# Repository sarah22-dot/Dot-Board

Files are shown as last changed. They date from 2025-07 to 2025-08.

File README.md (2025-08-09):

# Dot-Board
dot‑Board was never meant to be just another mechanical keyboard. It was built for a moment, for a vibe, for a challenge. The entire thing came together during Hack Club’s Highway event, where we were supposed to not just build something, but make it our own. I put my energy into what I love the most designing the PCB and modelling the case. While others were wiring or coding, I was deep inside Fusion 360 and EasyEDA Pro, trying to make sure every detail felt precise and intentional.

It started off as a late-night sketch in my notes app. I wanted something compact but not boring, logical but still unique. A grid layout made the most sense ortholinear, neat rows and columns, the kind of layout that just looks satisfying when you view it from topdown. I fired up EasyEDA Pro and began building the schematic from scratch. No template, no copy-paste from someone else's build. I dropped the Pro Micro, mapped each row and column with proper matrix logic, and added footprints for diodes and a rotary encoder. The goal was clarity and flow every trace should feel like it belongs.



Once the schematic was wired up, I moved to the PCB layout view and began placing the switches in a tight grid. I spent hours just nudging parts to get clean alignment. I added a compact reset switch footprint, labeled the layers carefully, and did final cleanup to make sure the silkscreen looked aesthetic. I chose 1.6 mm board thickness, standard FR4. Then I exported the Gerbers and submitted them to JLCPCB with the deadline pressure running in the back of my head.





At the same time, I jumped into Fusion 360 to work on the case. The case wasn’t just a box to hold the PCB it had to be clean, functional, and vibe with the layout. I designed a simple sandwich-style build, with a flat top plate that holds the switches snugly, and a lower base tray with screw mounts. I gave it slight curvature along the sides, nothing dramatic, just enough so it wouldn’t feel sharp in the hand. There was a cutout for the USB port and small standoffs inside so the board would sit at the right height without needing extra spacers.






The project wasn’t about perfection—it was about putting something together that you could be proud of. I didn’t assemble the keyboard physically, but seeing the design take shape and sharing it with others during the event felt like enough. I handed over the filesGerbers, STEP files, BOM references to the rest of the team or anyone who wanted to build it physically. It felt good knowing someone out there could finish what I started and maybe even add their own twist to it.



dot‑Board, to me, represents the kind of project that grows in a weekend but stays in your mind for a long time. The kind where you learn more by doing than reading. I figured out new quirks in EasyEDA, got better at 3D design in Fusion, and actually worked on finishing something under a deadline with that good kind of pressure. It’s not just a keyboard—it’s a slice of that Hack Club energy, captured in traces and plastic.





Even though I didn’t solder a single switch for this board, I still feel connected to every part of it because I designed it to work, to look sharp, and to invite others to complete it. That’s the spirit of dot‑Board. It starts with a dot, but you never know where it goes.

## updated case









## added logo on top


## BOM
| Component | Source & Link | Qty | Total Cost (INR) | Total Cost (USD) |
| --- | --- | ----- | --- | --- |
| Gateron Yellow Mechanical Switches | Amazon.in (70‑pack) | 62 | ₹2,400 | \$25 |
| PBT Dye‑sublimated Keycaps (Black) | neomacro.in | 62 | ₹2,550 | \$30 |
| Kailh Hot‑swap Sockets | neomacro.in | 62 | ₹1,300 | \$15.50 |
| Rotary Encoders | neomacro.in | 2 | ₹340 | \$4 |
| Encoder Knobs | neomacro.in | 2 | ₹170 | \$2 |
| Custom PCB (5 pcs) – Gerber\_Y51 | JLCPCB via EasyEDA  | 5 | ₹2,550 | \$30 |
| Arduino Pro Micro (Clone) | Amazon.in | 1 | ₹850 | \$10 |
| Diode Kit (1N4148, 100 pcs) | Amazon.in | 1 | ₹85 | \$1 |
| Screws, Standoffs, Mounting HW | Local/kit | 1 set | ₹150 | \$1.80 |
| Shipping (PCB from JLCPCB) | JLCPCB | 1 | ₹425 | \$5.33 |
| **Total** | | | **₹10,820** | **\$124.63** |

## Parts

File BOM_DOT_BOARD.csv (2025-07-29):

Component | Source & Link | Qty | Total Cost (INR) | Total Cost (USD)
Gateron Yellow Mechanical Switches | Amazon.in | 62 | 2400.0 | 25.0
PBT Dye‑sublimated Keycaps (Black) | neomacro.in | 62 | 2550.0 | 30.0
Kailh Hot‑swap Sockets | neomacro.in | 62 | 1300.0 | 15.5
Rotary Encoders | neomacro.in | 2 | 340.0 | 4.0
Encoder Knobs | neomacro.in | 2 | 170.0 | 2.0
Custom PCB (5 pcs) – Gerber_Y51 | JLCPCB via EasyEDA | 5 | 2550.0 | 30.0
Arduino Pro Micro (Clone) | Amazon.in | 1 | 850.0 | 10.0
Diode Kit (1N4148, 100 pcs) | Amazon.in | 1 | 85.0 | 1.0
Screws, Standoffs, Mounting HW | Local / Maker Kit | 1 set | 150.0 | 1.8
Shipping (PCB from JLCPCB) | JLCPCB | 1 | 425.0 | 5.33
Total |  |  | 10820.0 | 124.63

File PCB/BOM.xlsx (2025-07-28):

No. | Quantity | Comment | Designator | Footprint | Value | Manufacturer Part | Manufacturer | Supplier Part | Supplier
1 | 14 | C1206C105K5RACTU | C1,C2,C3,C4,C5,C6,C7,C8,C9,C10,C11,C12,C13,C14 | Capacitor_SMD:C_1206_3216Metric_Pad1.33x1.80mm_HandSolder
2 | 48 | 1N4148W | D1,D2,D3,D4,D5,D6,D7,D8,D9,D10,D11,D12,D13,D14,D15,D16,D17,D18,D19,D20,D21,D22,D23,D24,D25,D26,D27,D28,D29,D30,D31,D32,D33,D34,D35,D36,D37,D38,D39,D40,D41,D42,D43,D44,D45,D46,D47,D48 | Diode_SMD:D_SOD-123
3 | 10 | MountingHole | H1,H2,H3,H4,H5,H6,H7,H8,H9,H10 | kbd:M2_HOLE
4 | 2 | Conn_01x01_Female | J1,JN | Connector_Pin:Pin_D0.9mm_L10.0mm_W2.4mm_FlatFork
5 | 1 | Conn_01x03_Female | J3 | Connector_PinHeader_2.00mm:PinHeader_1x03_P2.00mm_Vertical
6 | 14 | WS2812B | LED1,LED2,LED3,LED4,LED5,LED6,LED7,LED8,LED9,LED10,LED11,LED12,LED13,LED14 | LED_SMD:LED_WS2812B_PLCC4_5.0x5.0mm_P3.2mm
7 | 1 | SW_KBD | Reset1 | kbd:SW_SPST_RS-282G05A3-SM
8 | 44 | MX_SW_HS | SW1,SW2,SW3,SW4,SW5,SW6,SW7,SW8,SW9,SW10,SW11,SW12,SW13,SW14,SW15,SW16,SW17,SW18,SW19,SW20,SW21,SW22,SW23,SW24,SW25,SW26,SW27,SW28,SW29,SW30,SW31,SW32,SW33,SW34,SW35,SW36,SW39,SW40,SW43,SW44,SW45,SW46,SW47,SW48 | Switch_Keyboard_Hotswap_Kailh:SW_Hotswap_Kailh_MX_1.00u
9 | 2 | RotaryEncoder_Switch | SW37,SW38 | Rotary_Encoder:RotaryEncoder_Alps_EC11E-Switch_Vertical_H20mm
10 | 2 | MX_SW_HS | SW41,SW42 | Switch_Keyboard_Hotswap_Kailh:SW_Hotswap_Kailh_MX_1.50u_90deg
11 | 1 | MSK12C02 | SW49 | kbd:MSK12C02
12 | 1 | SS12D00 | SW_TOG1 | kbd:SS12D00
13 | 1 | ProMicro | U1 | kbd:ProMicro_v3.5

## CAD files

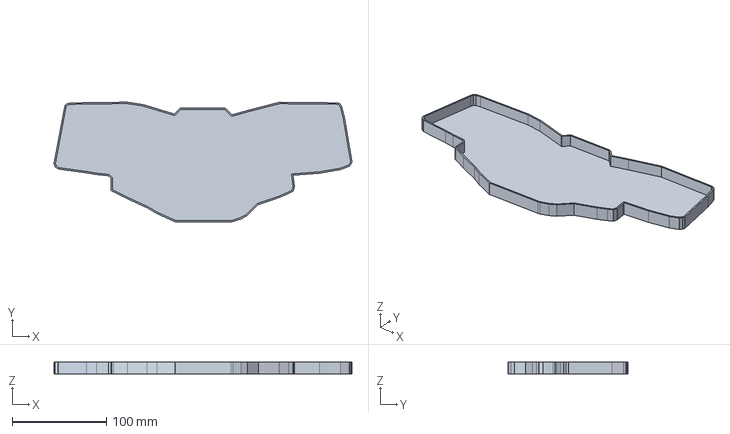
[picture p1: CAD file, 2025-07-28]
CAD/Back.step
317.0 x 127.4 x 12.7 mm

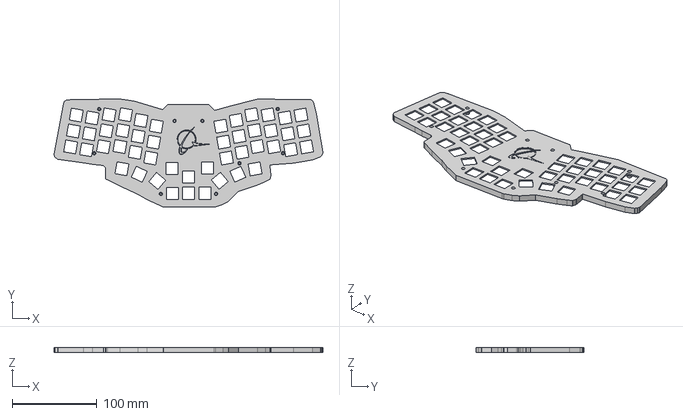
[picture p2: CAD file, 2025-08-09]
Production/Top v2.step
317.0 x 127.4 x 6.35 mm

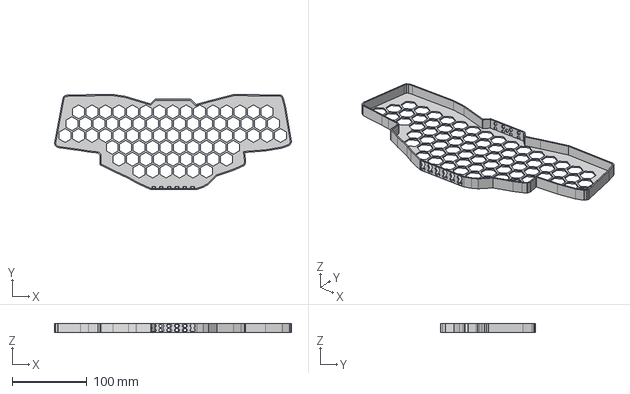
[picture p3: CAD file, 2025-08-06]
Production/base v2.step
317.0 x 127.4 x 12.7 mm

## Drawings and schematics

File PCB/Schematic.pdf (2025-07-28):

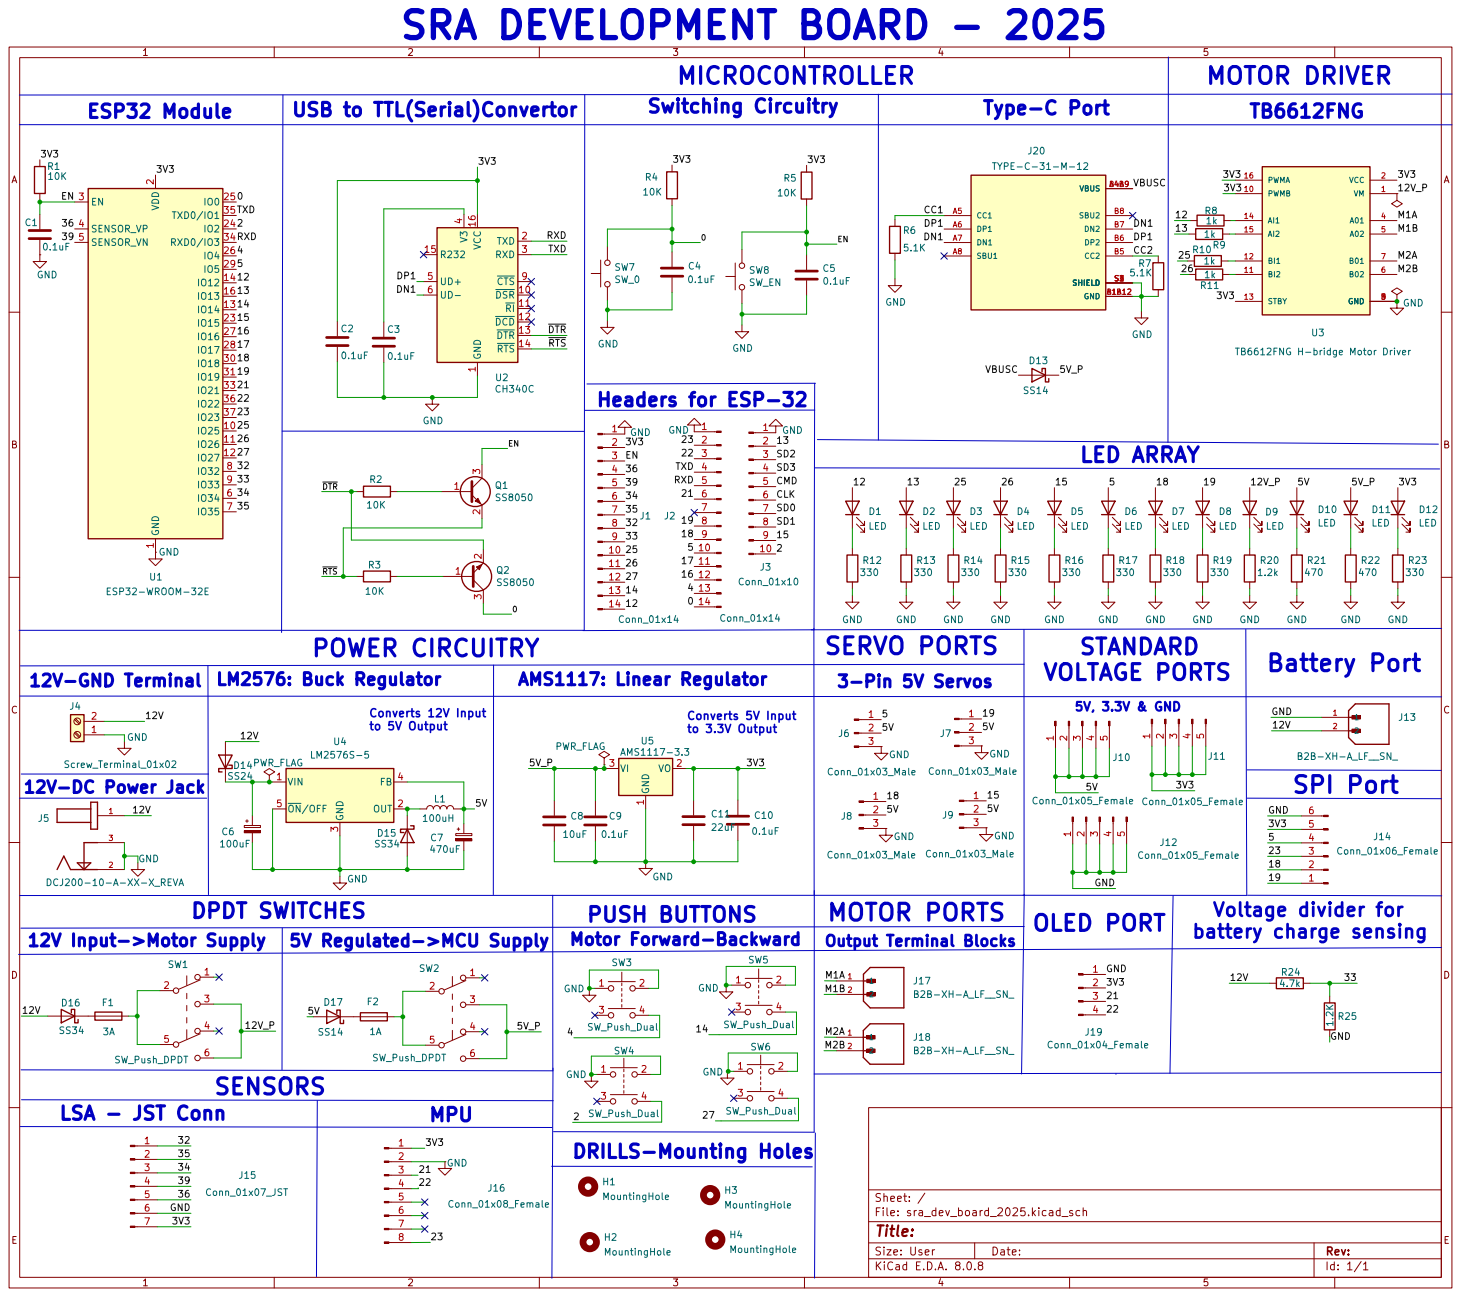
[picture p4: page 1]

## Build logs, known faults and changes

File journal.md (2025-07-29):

## Dot‑Board Build Journal
---
Title: "Dot Board"
Author: "Sarah"
Description: "Custom keeeb
created_at: "2025-07-25"
Total time spent: 22.5
---

## July 22 – First Schematic (7.5 hours)
It was one of those nights when the rain had just stopped, my playlist was stuck on Lo-fi beats, and I was just sitting on my bed, staring at my half dead old keyboard. The thing looked like it had survived a zombie apocalypse. And the typing feel? Ugh, don’t even ask. Every keystroke felt like I was arguing with a soggy biscuit. That’s when something clicked. Not on the keyboard, though. In my brain. I thought, “Why not just make my own keyboard?” Not just assemble parts, but actually design everything—the PCB, the schematic, and the whole look. And thus, the dot‑Board idea was born, right there under my cheap fairy lights.

I opened up EasyEDA Pro and started a new project called “dot-Board v0.” No fancy names, just straight to the point. First, I decided I wanted something clean and minimal, like the Apple aesthetic but with actual soul. The layout in my mind was around 60%, no extra fluff, just pure keys and function. I dropped in a Pro Micro clone in the schematic view yeah, the classic one. I know it’s old, but it works.



Then came the diodes. I started building out the switch matrix, row by row. Seven rows, five columns nothing too crazy, but enough to feel custom. I carefully placed each 1N4148 diode in series with the switches, making sure the cathode was facing away from the MCU. I’ve messed that up before, trust me, it’s not fun to desolder thirty mistakes. I labelled every net properly this time: ROW0 to ROW6, COL0 to COL4. No shortcuts.



By the time I ran the ERC, the clock had struck 3:30 AM. Zero errors. That moment felt like my brain gave me a high five. I exported the netlist and called it a night, but I already knew tomorrow was going to be all about PCB layout and chai.

## July 24 – PCB Layout and Routing Grind (9 hours)
The next morning—or should I say afternoon—I woke up at 1 PM. Still slightly groggy, but as soon as I saw my notebook filled with layout sketches, I snapped out of it. I booted up EasyEDA’s PCB view and imported the schematic. All the footprints were floating around like pieces of a puzzle. The default board outline was a random square, so I quickly changed it to a custom 280 × 95 mm shape. That size gave me enough breathing room for key spacing while keeping it compact on my desk.



The first thing I anchored down was the Pro Micro. I placed it bottom center, with enough clearance on the USB side for a front facing cutout. Then I lined up the switch footprints. This was the most satisfying part. Dragging and dropping each MX switch pad onto the grid, making sure the spacing was exactly 19.05 mm apart, and aligning everything to perfection. I kept imagining the keycaps I’d put on later. I left space on the top-right corner for an OLED too even though I hadn’t added it to the schematic yet. I might revise it later.

Next, I routed the power rails. Thick 32mil traces for GND and VCC, branching out from the USB-C breakout area. I used via stitching to link the top and bottom GND planes, then filled the rest of the space with ground copper pour. For the switch matrix, I went with 10mil traces for both rows and columns. I routed the rows on the top layer and the columns on the bottom, jumping between layers using vias whenever traces got tight.



Around hour four, things started to get messy. A couple of nets refused to cooperate—they kept auto‑snapping to weird corners. I switched off the autorouter and did everything manually, nudging each trace pixel by pixel. For the optional buzzer, I made a small zone in the bottom left corner. I added an M3 mounting hole near each board corner, placed evenly from the edges, and added a silkscreen logo right above the Pro Micro area.

I enabled 3D preview and took a deep breath. Seeing the board in black solder mask with sharp white silkscreen lines made me smile like a madman. It felt like the digital version of holding your own invention. I tweaked the mounting hole alignment once again, ran the DRC, and fixed the last few overlapping traces.



## July 25 – Bill of Materials and Case Design (5 hours)
I started the day with a mug of hot coffee and an Excel sheet open in front of me. The dreaded BOM. Everyone skips it till the end, but I wanted to get it done early. I listed out every component I used and where I’d get it from.

Sixty‑one Outemu Red switches, ₹1,850 from cosmicbyte.in. A solid set of PBT keycaps, ₹2,450 from neomacro.in. Hot‑swap sockets from Shaarvi Electronics, ₹1,150 for a pack of seventy. The Pro Micro clone, ₹800 on Amazon. Diodes, ₹90. A pack of resistors and caps, ₹130. USB-C breakout, ₹200. Screws, standoffs, and plastic feet, ₹180 total. After some rounding, the grand total stood close to ₹8,900, or around $107. Not bad for a full custom board that’s all mine.



Then I moved on to Fusion 360. The PCB outline was already clear in my head. I sketched the base plate, made it 3mm thick, then extruded the sidewalls to 11mm. I added slots for every key switch, rectangular holes for the stabilizers, and a front cutout for the USB-C port. On the top side, I gave each key a perfect 15×15mm hole, spaced just right. The mounting holes were easy to align using the PCB measurements.



I made a second body for the bottom case, this time with screw posts that matched the standoff placements on the PCB. I used the Combine tool to cut matching holes and tested everything using joints. No interference, no overlaps. Then I added a subtle side logo that says “dot-Board” in lowercase, using the Text tool and extruding it just 0.5mm out.



Finally, I exported both STL files and dropped them into Cura. At 0.2mm layer height, each half would take about 4.5 hours to print. I configured the bed layout for my Ender 3 and saved the G-code. It was around 7 PM by the time I shut down Fusion. I hadn’t even printed anything yet, but seeing the rendered preview made me whisper: “You’re real now, buddy.”










July 26 – QMK Firmware Setup (1 hour)
With the design all set and the STL files ready to print, I decided to dive into the firmware part—at least the initial setup—because I wanted to lock in the layout while it was still fresh in my head. I opened up the QMK Configurator and began mapping the layout exactly as I imagined it during design. All the main keys were straightforward, and I kept things clean: a compact typing layout on layer 0, and a secondary layer for arrow keys, volume control, and maybe media playback later on.
I added a function key to toggle layers, set up MO(1) on the bottom row, and assigned RESET to one of the top-right keys—just in case I needed it during flashing. Even though I hadn't hooked up the board yet, it felt cool seeing the visual layout evolve into something that was truly mine. Once everything looked solid, I downloaded the .hex and .json files and saved them in my firmware folder labeled “dot‑Board_v0”.
